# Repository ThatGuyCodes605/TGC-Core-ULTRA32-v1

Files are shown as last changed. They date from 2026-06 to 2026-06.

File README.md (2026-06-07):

# TGC-Core-ULTRA32-v1

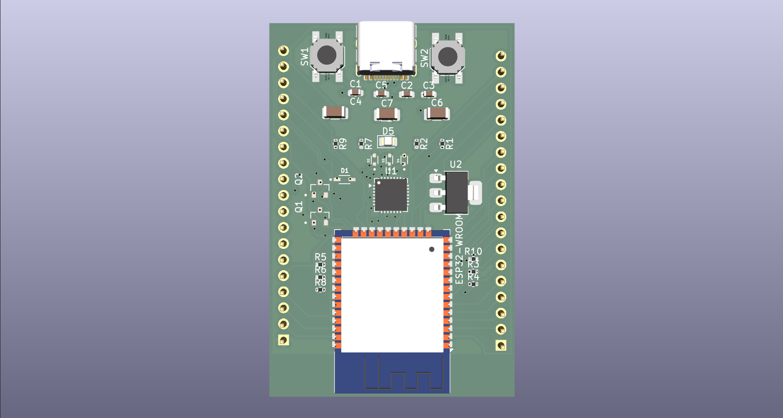
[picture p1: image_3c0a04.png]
Board Render


## Overview
The **TGC-Core-ULTRA32-v1** is an open-source, high-performance hardware development core board based on the **ESP32** platform. Engineered for wireless application prototyping and IoT deployment, [...]

This repository contains the complete set of KiCad EDA files (version 10.0) necessary to view, modify, or manufacture the printed circuit board (PCB).

---

## Key Hardware Features

* **Microcontroller Core:** Powered by an **ESP32-WROOM-32** module, featuring a dual-core 32-bit Xtensa LX6 processor running up to 240 MHz.
* **Wireless Capabilities:** Integrated **Wi-Fi** (802.11 b/g/n) and dual-mode **Bluetooth** (Classic & BLE) with an onboard PCB trace antenna.
* **Seamless Programming:** Features an onboard **CP2102N** USB-to-UART master bridge chip, enabling effortless code flashing and hardware debugging.
* **Modern Power & Data Interface:** Equipped with a physical **USB Type-C** connector wired for high-reliability USB 2.0 configuration.
* **Onboard Power Regulation:** An onboard **AMS1117-3.3** Low Dropout (LDO) linear regulator steps down 5V VBUS power to a stable 3.3V rail capable of driving up to 1A.
* **Prototyping Breakout:** System pins and GPIO extensions are cleanly routed out to a generic single-row 19-pin hardware header (`Conn_01x19`).
* **PCB Specifications:** A robust 4-layer FR4 signal stackup engineered for optimal routing paths, power decoupling, and signal integrity.

---

## Repository Structure

The project is entirely self-contained within the following native KiCad design files:

| File Name | Description |
| :--- | :--- |
| `TGC-Core-ULTRA32-v1.kicad_pro` | The main **KiCad Project file**. Open this file to initialize the system workspace. |
| `TGC-Core-ULTRA32-v1.kicad_sch` | The **Schematic file**. Outlines the logical connections between the ESP32, CP2102N bridge, and power stages. |
| `TGC-Core-ULTRA32-v1.kicad_pcb` | The **PCB Layout file**. Houses the physical 4-layer trace configurations, via sizing, and physical board outlines. |
| `image_3c0a04.png` | A visual reference render of the completed board layout. |

---

## Getting Started

### 1. Hardware Inspection and Design
To view or modify the hardware design layout:
1. Download and install [KiCad EDA](https://www.kicad.org/) (ensure you are using KiCad v10 or newer to parse the modern project syntax).
2. Open the `TGC-Core-ULTRA32-v1.kicad_pro` file.
3. Launch the Schematic Editor or PCB Layout Editor to inspect components, footprints, and the default 4-layer layout structure.

### 2. Programming Setup
Because this core board uses standard ESP32-WROOM-32 pinouts and a CP2102N UART controller, it functions natively inside the ESP32 firmware environment:
1. Install the [Arduino IDE](https://www.arduino.cc/en/software) or configure an environment in **VS Code / PlatformIO**.
2. Add the ESP32 board package URL to your environments manager if using the Arduino IDE.
3. Connect the hardware core via a standard USB-C cable.
4. Under **Tools > Board**, select **"ESP32 Dev Module"** (or generic ESP32 WROOM module).
5. Match the assigned serial port and deploy your firmware sketches normally.

---

## License

This hardware design and its accompanying documentation are licensed under the **GNU General Public License v3.0 (GPL-3.0-or-later)**.

Summary of your rights under GPLv3:
* You are free to use, study, share, and modify the material.
* If you distribute the work (or a derivative), you must license the whole work under GPLv3 as well (share-alike).
* You must provide source for distributed derivative works and include the GPLv3 license text and copyright notices.

For the full legal text, see the GNU licenses page: https://www.gnu.org/licenses/gpl-3.0.html

Note: To make the change complete, consider adding a `LICENSE` file containing the full GPLv3 text and an explicit copyright line (for example: "Copyright (c) 2026 ThatGuyCodes605"). I can add that file for you if you want.

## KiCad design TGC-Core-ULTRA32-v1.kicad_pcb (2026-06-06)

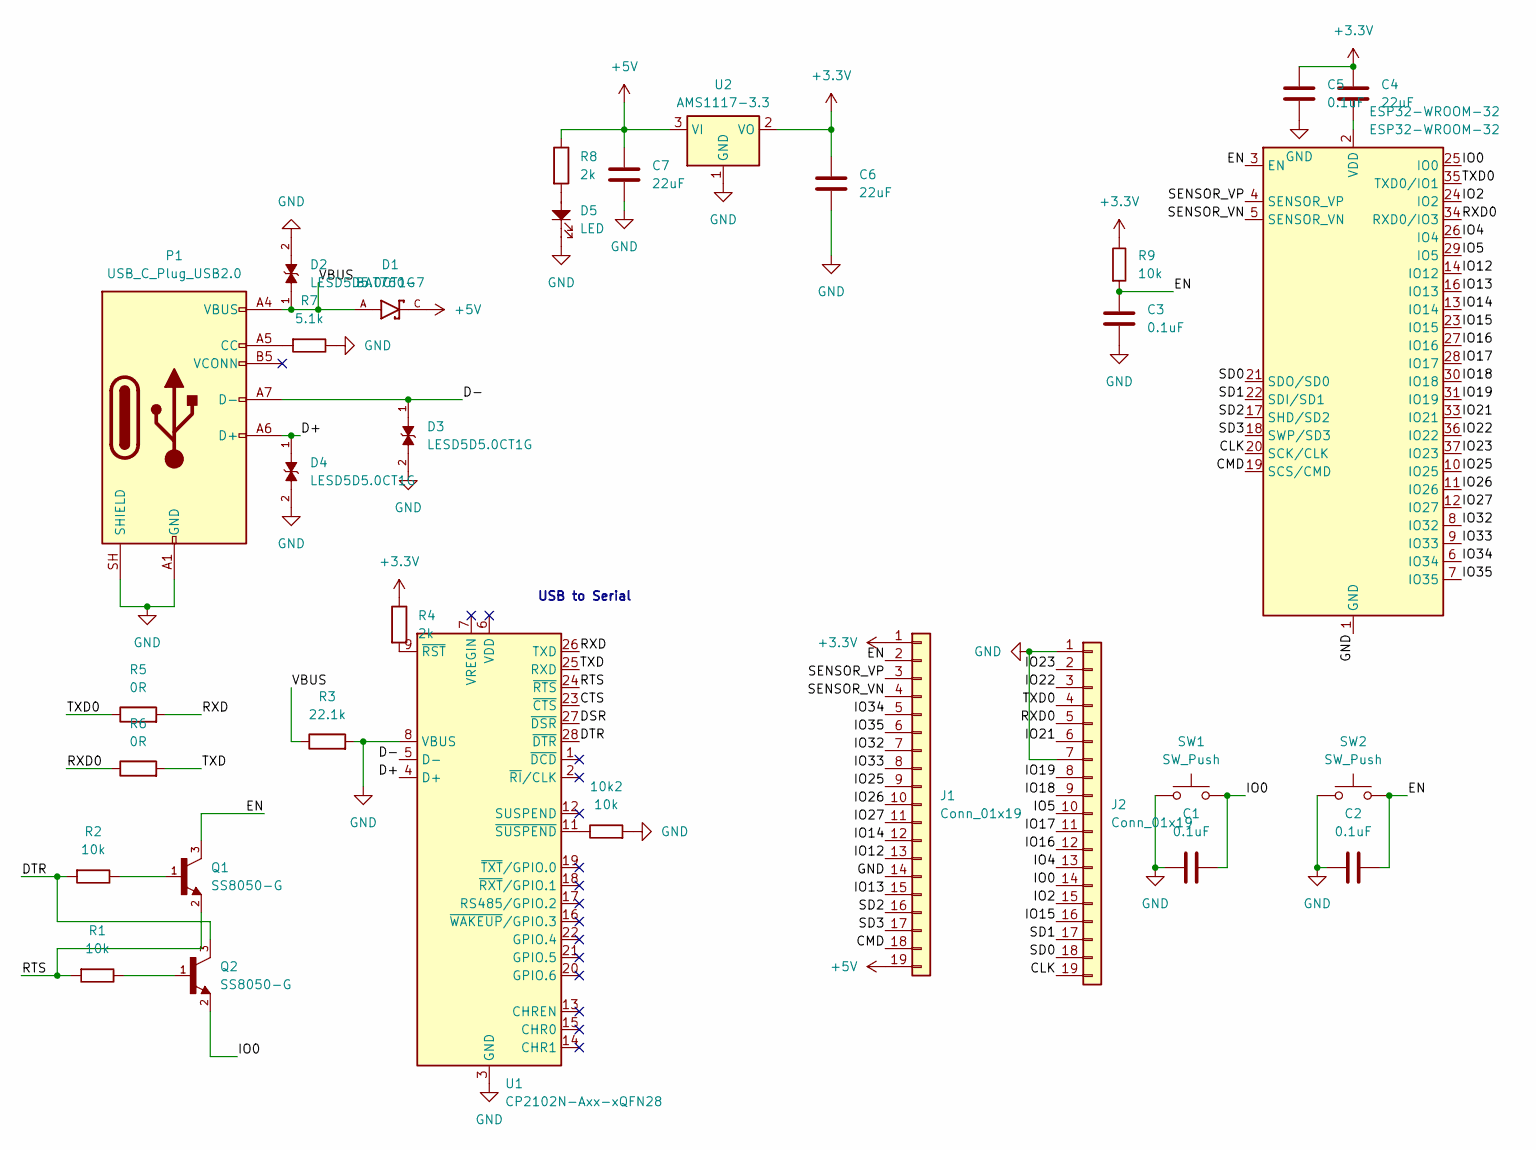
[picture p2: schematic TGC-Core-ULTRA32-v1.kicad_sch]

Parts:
10k2: 10k; R_0402_1005Metric
C1, C2, C3, C5: 0.1uF; C_0603_1608Metric
C4, C6, C7: 22uF; C_1206_3216Metric
D1: BAT760-7; SOD2513X120N; PARTREV 9-2
D2, D3, D4: LESD5D5.0CT1G; TVS_LESD5D5.0CT1G; PARTREV O
D5: LED; LED_0805_2012Metric
ESP32-WROOM-32: ESP32-WROOM-32
J1, J2: Conn_01x19; PinHeader_1x19_P2.54mm_Vertical
P1: USB_C_Plug_USB2.0; USB_C_Receptacle_HRO_TYPE-C-31-M-12
Q1, Q2: SS8050-G; TRANS_SS8050-G; PARTREV A
R1, R2, R9: 10k; R_0402_1005Metric
R3: 22.1k; R_0402_1005Metric
R4, R8: 2k; R_0402_1005Metric
R5, R6: 0R; R_0402_1005Metric
R7: 5.1k; R_0402_1005Metric
SW1, SW2: SW_Push; SW_SPST_SKQG_WithoutStem
U1: CP2102N-Axx-xQFN28; QFN-28-1EP_5x5mm_P0.5mm_EP3.35x3.35mm
U2: AMS1117-3.3; SOT-223-3_TabPin2

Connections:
+3.3V: C4.1, C5.1, C6.1, J1.1, R4.1, R9.2, U2.2 (VO)
+5V: C7.1, D1.C, J1.19, R8.1, U2.3 (VI)
/CLK: ESP32-WROOM-32.20 (SCK/CLK), J2.19
/CMD: ESP32-WROOM-32.19 (SCS/CMD), J1.18
/CTS: U1.23 (~CTS)
/D+: D4.1, P1.A6 (D+), U1.4 (D+)
/D-: D3.1, P1.A7 (D-), U1.5 (D-)
/DSR: U1.27 (~DSR)
/DTR: Q2.3, R2.1, U1.28 (~DTR)
/EN: C2.1, C3.1, ESP32-WROOM-32.3 (EN), J1.2, Q1.3, R9.1, SW2.2
/IO0: C1.1, ESP32-WROOM-32.25 (IO0), J2.14, Q2.2, SW1.2
/IO2: ESP32-WROOM-32.24 (IO2), J2.15
/IO4: ESP32-WROOM-32.26 (IO4), J2.13
/IO5: ESP32-WROOM-32.29 (IO5), J2.10
/IO12: ESP32-WROOM-32.14 (IO12), J1.13
/IO13: ESP32-WROOM-32.16 (IO13), J1.15
/IO14: ESP32-WROOM-32.13 (IO14), J1.12
/IO15: ESP32-WROOM-32.23 (IO15), J2.16
/IO16: ESP32-WROOM-32.27 (IO16), J2.12
/IO17: ESP32-WROOM-32.28 (IO17), J2.11
/IO18: ESP32-WROOM-32.30 (IO18), J2.9
/IO19: ESP32-WROOM-32.31 (IO19), J2.8
/IO21: ESP32-WROOM-32.33 (IO21), J2.6
/IO22: ESP32-WROOM-32.36 (IO22), J2.3
/IO23: ESP32-WROOM-32.37 (IO23), J2.2
/IO25: ESP32-WROOM-32.10 (IO25), J1.9
/IO26: ESP32-WROOM-32.11 (IO26), J1.10
/IO27: ESP32-WROOM-32.12 (IO27), J1.11
/IO32: ESP32-WROOM-32.8 (IO32), J1.7
/IO33: ESP32-WROOM-32.9 (IO33), J1.8
/IO34: ESP32-WROOM-32.6 (IO34), J1.5
/IO35: ESP32-WROOM-32.7 (IO35), J1.6
/RTS: Q1.2, R1.1, U1.24 (~RTS)
/RXD: R5.2, U1.26 (TXD)
/RXD0: ESP32-WROOM-32.34 (RXD0/IO3), J2.5, R6.1
/SD0: ESP32-WROOM-32.21 (SDO/SD0), J2.18
/SD1: ESP32-WROOM-32.22 (SDI/SD1), J2.17
/SD2: ESP32-WROOM-32.17 (SHD/SD2), J1.16
/SD3: ESP32-WROOM-32.18 (SWP/SD3), J1.17
/SENSOR_VN: ESP32-WROOM-32.5 (SENSOR_VN), J1.4
/SENSOR_VP: ESP32-WROOM-32.4 (SENSOR_VP), J1.3
/TXD: R6.2, U1.25 (RXD)
/TXD0: ESP32-WROOM-32.35 (TXD0/IO1), J2.4, R5.1
/VBUS: D1.A, D2.1, P1.A4 (VBUS), P1.A9 (VBUS), P1.B4 (VBUS), P1.B9 (VBUS), R3.1
GND: 10k2.1, C1.2, C2.2, C3.2, C5.2, C6.2, C7.2, D2.2, D3.2, D4.2, D5.1, ESP32-WROOM-32.1 (GND), ESP32-WROOM-32.15 (GND), ESP32-WROOM-32.38 (GND), ESP32-WROOM-32.39 (GND), J1.14, J2.1, J2.7, P1.A1 (GND), P1.A12 (GND), P1.B1 (GND), P1.B12 (GND), P1.SH (SHIELD), R3.2, R7.2, SW1.1, SW2.1, U1.3 (GND), U1.8 (VBUS), U1.29 (GND), U2.1 (GND); also elsewhere on the board
unnamed: D5.2, R8.2
unnamed: C4.2, ESP32-WROOM-32.2 (VDD)
unnamed: P1.A5 (CC), R7.1
unnamed: Q1.1, R2.2
unnamed: Q2.1, R1.2
unnamed: R4.2, U1.9 (~RST)
unnamed 51: 10k2.2, U1.11 (~SUSPEND); also elsewhere on the board

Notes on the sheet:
USB to Serial

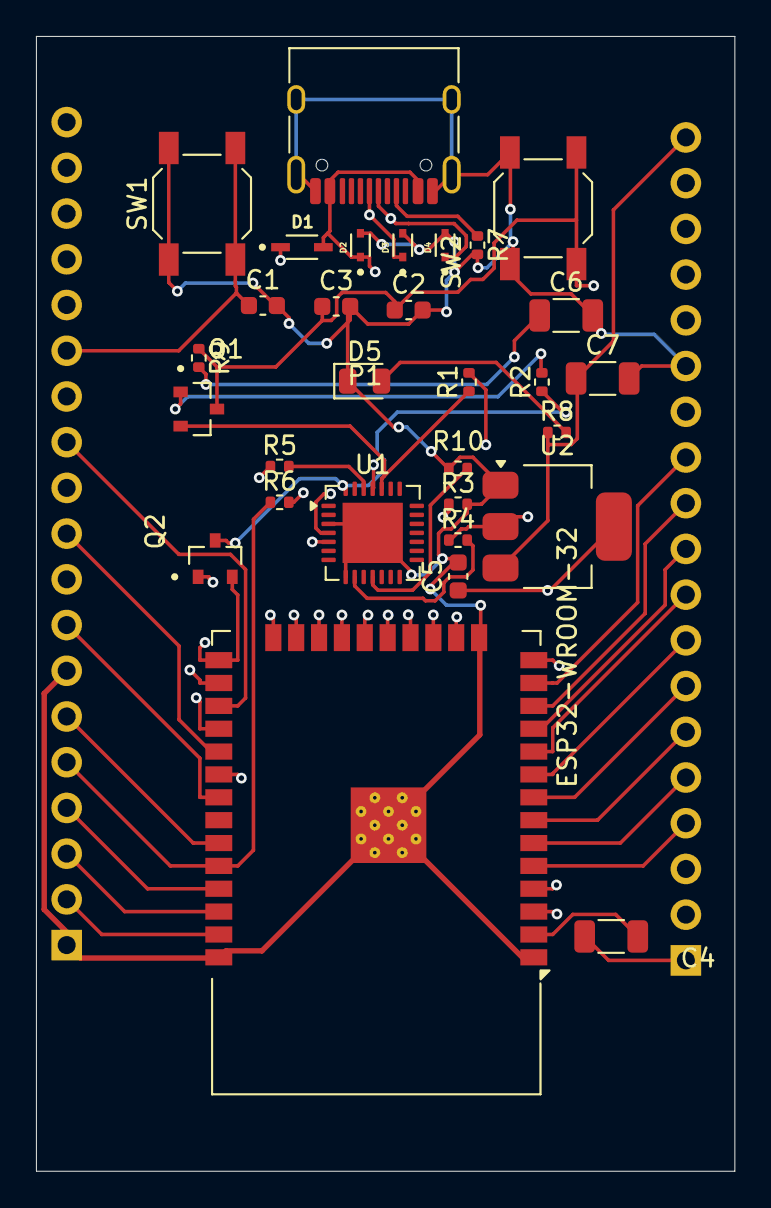
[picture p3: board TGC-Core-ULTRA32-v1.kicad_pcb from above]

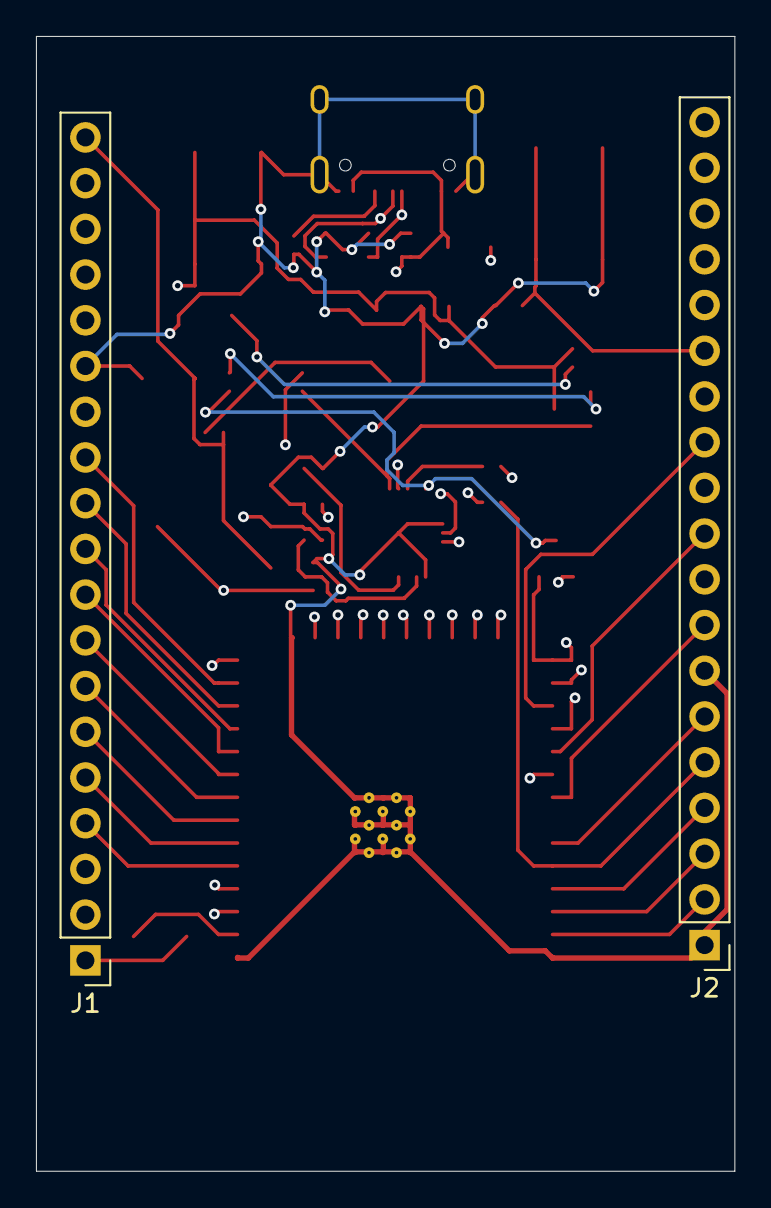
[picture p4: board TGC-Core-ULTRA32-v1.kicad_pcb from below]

Board: 4 copper layers, 38.8 x 63.0 mm, 32 parts (2 on the bottom side), 50 nets.

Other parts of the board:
R10: 10k; R_0402_1005Metric

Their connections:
GND: R10.1; also elsewhere on the board
unnamed 51: R10.2; also elsewhere on the board
